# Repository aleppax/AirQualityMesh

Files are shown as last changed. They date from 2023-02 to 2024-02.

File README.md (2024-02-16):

# outdoor air quality station opms logo

current development status: [Proof of Concept.](roadmap.md)

IoT system monitoring outdoor air quality with multiple stations, remote data collection and analytics.
It can work both as a stationary or a roving unit, logging datetime, position and sensor data.

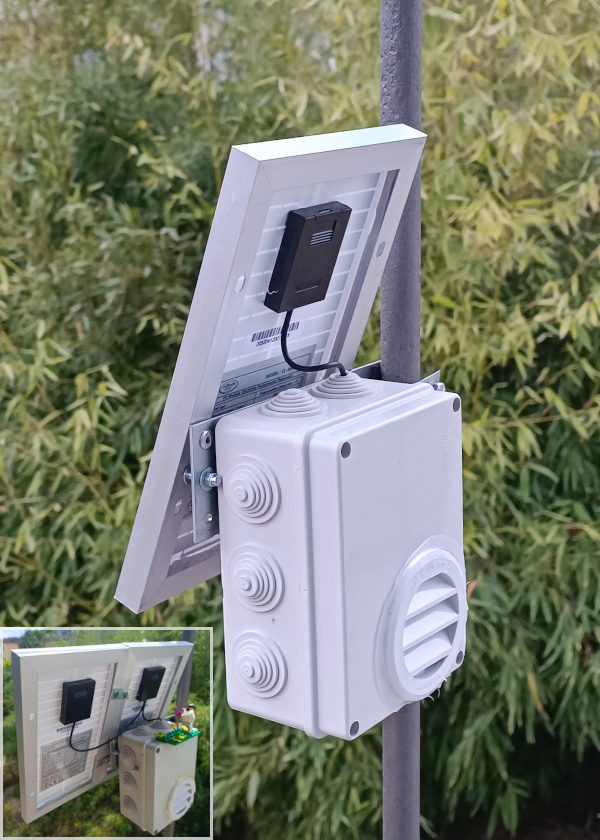
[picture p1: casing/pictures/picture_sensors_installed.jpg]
mainboard rendering an external photo of the installed system


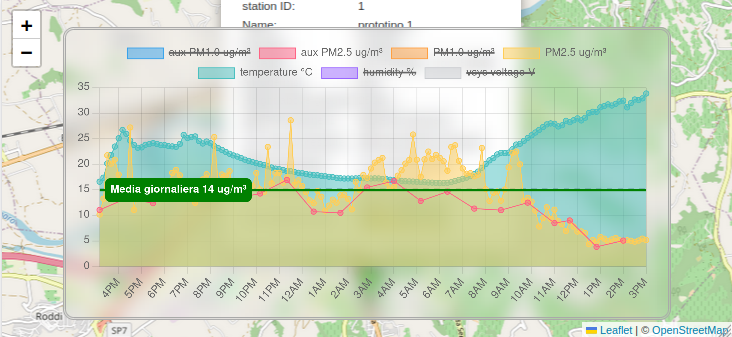
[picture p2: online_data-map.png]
data visualization online charto of data from a single station


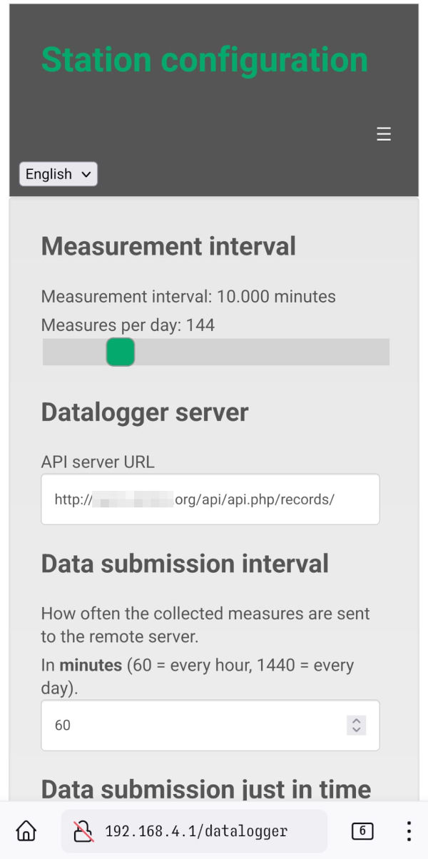
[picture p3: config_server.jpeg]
station configuration on board configuration webserver


## Supported sensors 

|sensor| description | physical dimensions| max connected sensors |
|--|--|--|--|
| pms5003 | PM Sensor PMS5003 | pm1.0 pm2.5 | 2 |
| pms5003T | PM Sensor PMS5003T | pm1.0 pm2.5 humidity temperature | 2 |
| sngcja5 | PM Sensor SN-GCJA5 | pm1.0 pm2.5 | 1 |
| sps30 | PM Sensor SPS30 | pm1.0 pm2.5 | 1 |
| bmp280 | Pressure sensor BMP280 | barometric pressure | 1 |
| aht20 | Humidity and Temperature Sensor AHT20 | humidity temperature | 1 |

* there is an overall max number of 2 connected PM sensors at the same time, regardless of the model. The limit is software, therefore it can be overcome.

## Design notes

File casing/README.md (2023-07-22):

## PCB
 
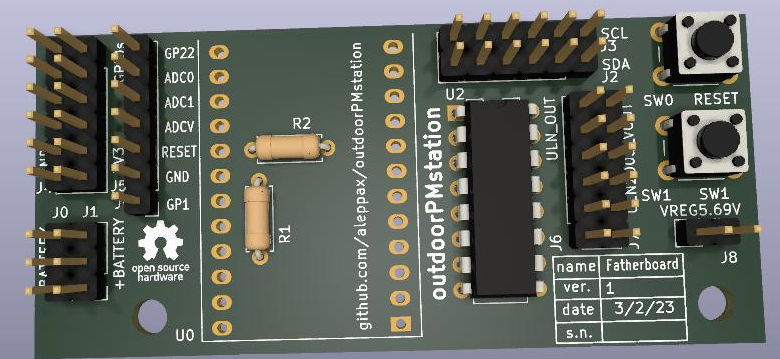
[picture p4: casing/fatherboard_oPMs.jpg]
mainboard rendering mainboard


The PCB design is single sided, has no SMD parts and a minimalistic BOM. Components are on the opposite side of the copper layer. 
Hence it is very straightforward to make it at home both with a CNC or chemicals. 
The main purpose of the PCB is to speed up the assembly but it is better to choose 
terminals that guarantee contact continuity over time since this is an outdoor application partially exposed to weather conditions.
The two resistors are 20K and 30K Ohm, they are used as an external voltage divider to measure the battery voltage. 
We decided to avoid using the internal ADC3 with its own voltage divider because this relies on the WL_GPIO2 of the wireless chip and we didn't want conflicts during wifi communication. If a good precision isn't paramount it is possible to stop using the external circuit in favor of the builtin one.

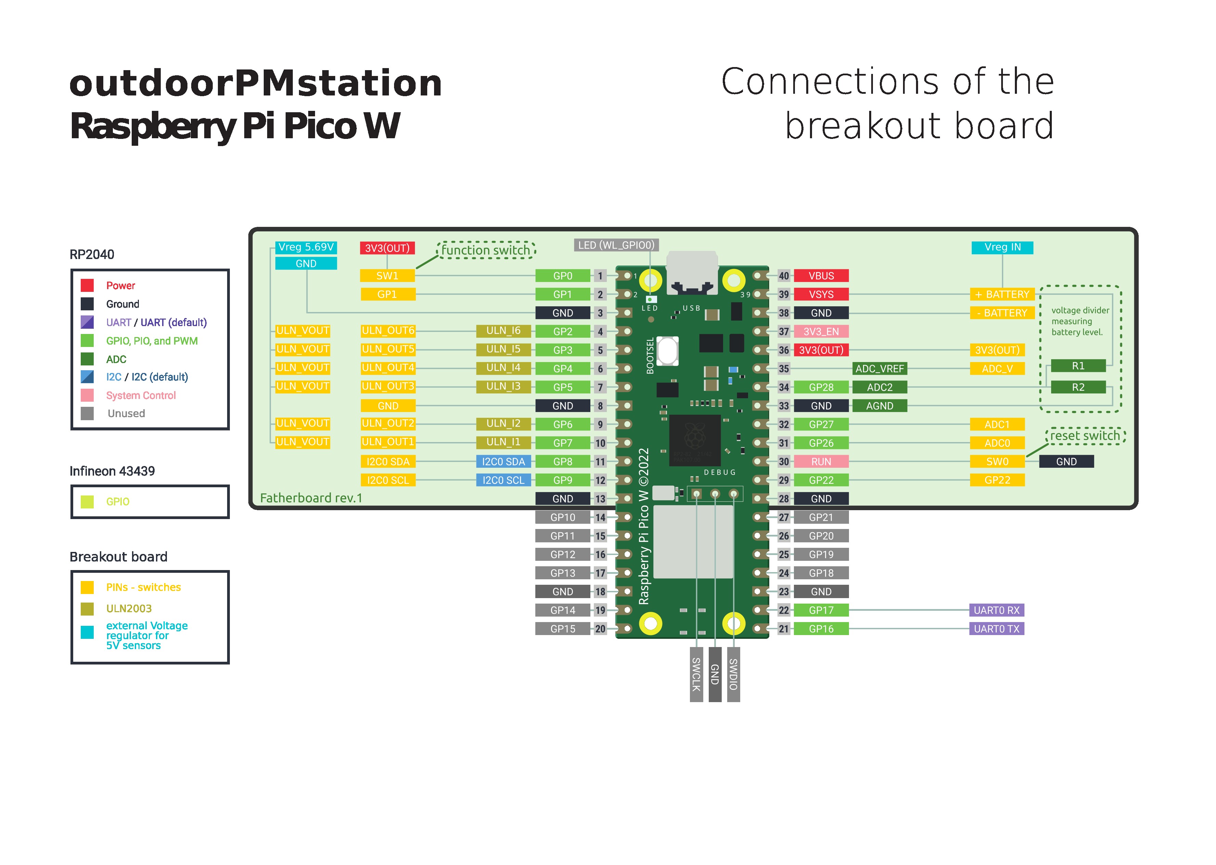
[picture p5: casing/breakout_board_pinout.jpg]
breakout board pinout breakout board


The connection PCB has been designed so that half of the Raspberry Pico, the part where the antenna is located, protrudes, so as to move connection wires and tracks away as far as possible from the transceiver area.

## Case

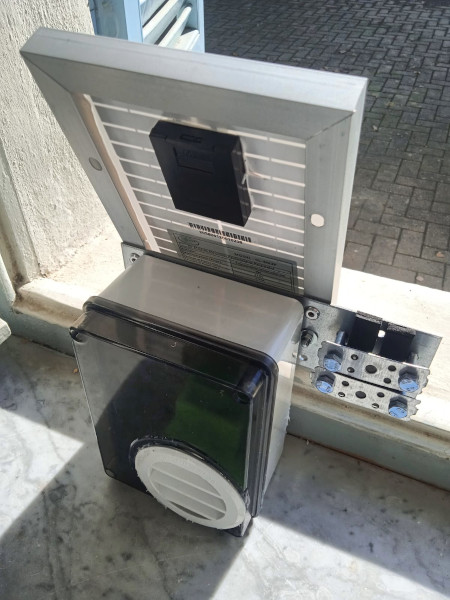
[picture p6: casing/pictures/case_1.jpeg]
front view case front view

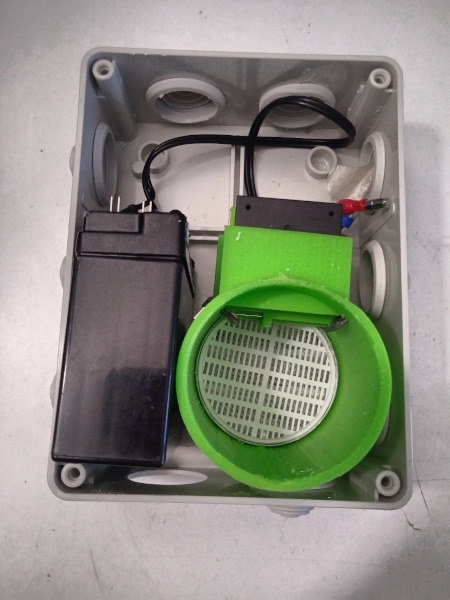
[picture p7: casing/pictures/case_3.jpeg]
battery view 4V battery inside


the casing is designed to be composed mainly of cheap parts available from electrical component suppliers, for which a compact junction box was chosen (150 X 110 X 70 mm, IP 56), commercially available air vents (to which a double layer of mosquito netting was added for greater protection from small insects). Each air vent has an overall opening of 8 cm^2.

## Solar panel

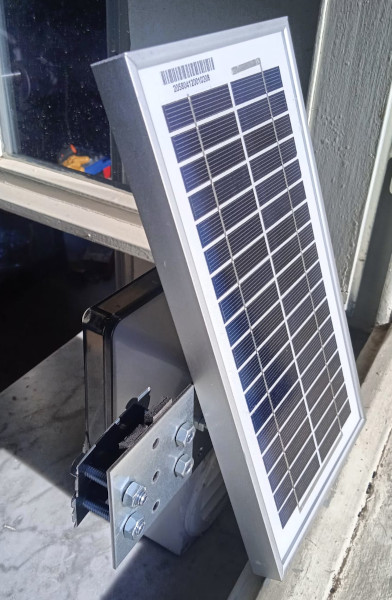
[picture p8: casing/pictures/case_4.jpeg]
rear view case rear view


The solar panel (Cellevia CL-SM3P) is extremely cheap but still slightly oversized, it has the secondary function of protecting the casing from direct solar radiation and has an aluminum frame for easier fixing.

## Fixing 

A sturdy joint plate with screws and nuts for fixing to a post or railing or fence. Different fixing systems will have to be studied according to the location.

## Sensor holder

The only customized component is the sensor fixing structure which allows to house two particulate sensors and possibly a humidity and temperature sensor. Subsequent redesigns could accommodate a small fan in case it is necessary to force a greater air exchange.

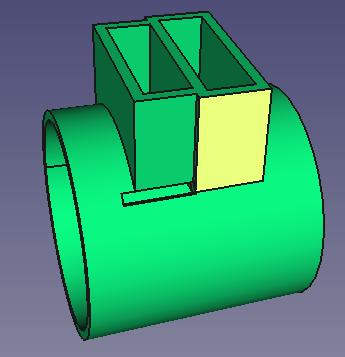
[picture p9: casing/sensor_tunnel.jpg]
mainboard rendering sensor tunnel

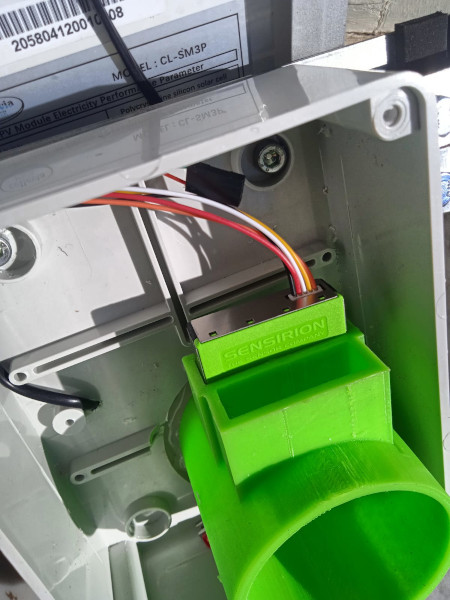
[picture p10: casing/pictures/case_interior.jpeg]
interior case interior view

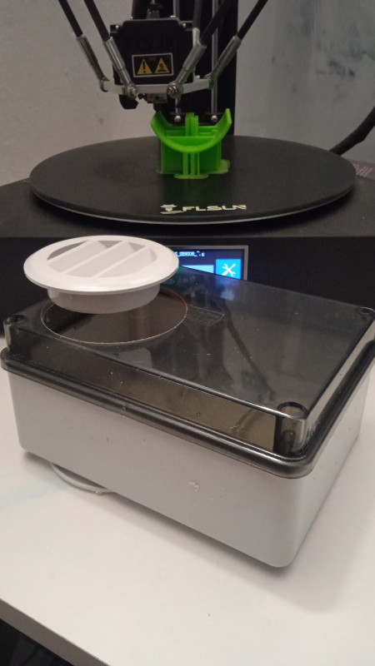
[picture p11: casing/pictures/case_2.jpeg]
assembly 3D printing the sensor holder


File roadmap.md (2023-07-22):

# Roadmap

## Early Proof of Concept

we are investigating many possibilities and the purpose of this stage is to define a roadmap for the Proof of Concept

## Proof of Concept -CURRENT-

At this stage the project is emerging from a glowing cauldron, nothing is permanent and the overall structure of the system is in progress.
We are currently evaluating:
 - [x] WiFi network, data queue, main routine
 - [x] acting as an Access Point and web server to configure the SSID and password from the user (unsecured) and other settings 
 - [x] MQTT connection,REST API
 - [ ] selection of parameters and launch of side projects: humidity, temperature, wind, PM, sound pressure level, traffic counter.
 - [ ] testing sensors: particle matter, sound, wind
 - [ ] batteries, solar panels and power regulators

the purpose of this stage is to define a roadmap for a Minimum Viable Product

## Minimum Viable Product

A minimum working configuration 

 - [x] is powered by battery or power supply and optimizes current usage
 - [x] has a simple case (e.g. a junction box) suitable for outdoor usage
 - [x] allows the user to see sensor measures, setup the WiFi connection and global coordinates via a web interface
 - [x] sync its RTC wit NTP servers
 - [x] update the software if available
 - [x] reads sensors data according to the schedule
 - [x] stores data into a queue when network is unreachable 
 - [x] send measurements via ~~existing (sensors.community)~~ and custom APIs or mqtt to a public server
 - [x] receive and display data to a Home Assistant server
 - [ ] basic documentation

# Alpha

 - [ ] project structure pruning and refactoring
 - [ ] software test coverage and debugging
 - [ ] define features and technical details
 - [ ] define metrological details (operating range, uncertainty, redundancy, metrological traceability, calibration) sensors are not black boxes.
 - [ ] design and test of the enclosure, internal layout, bug-proof and water tightness, thermal performance with different climatic conditions and solar exposition
 - [ ] standard visualization via hosted web server
 - [ ] comprehensive documentation and community involvement 
 
# beta
- optional network connection via GSM - LoRa wan.
- test with the help of early users
- collect data
- improved access point interface
- improved visualization server side via Leaflet

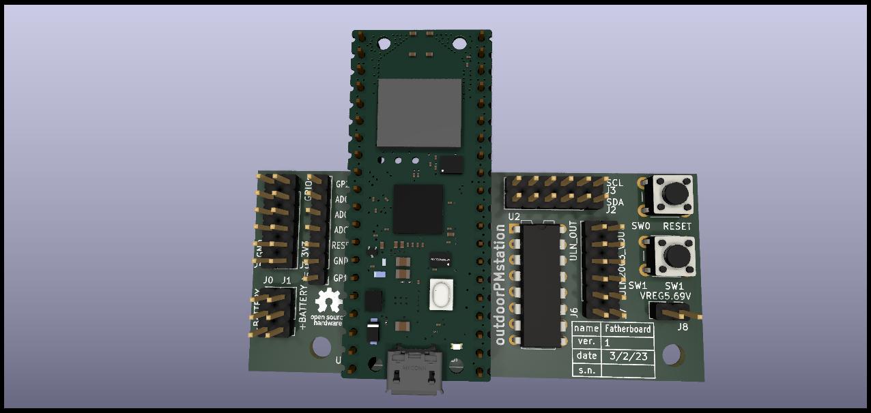
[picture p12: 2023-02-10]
fatherboard_oPMs2.jpg

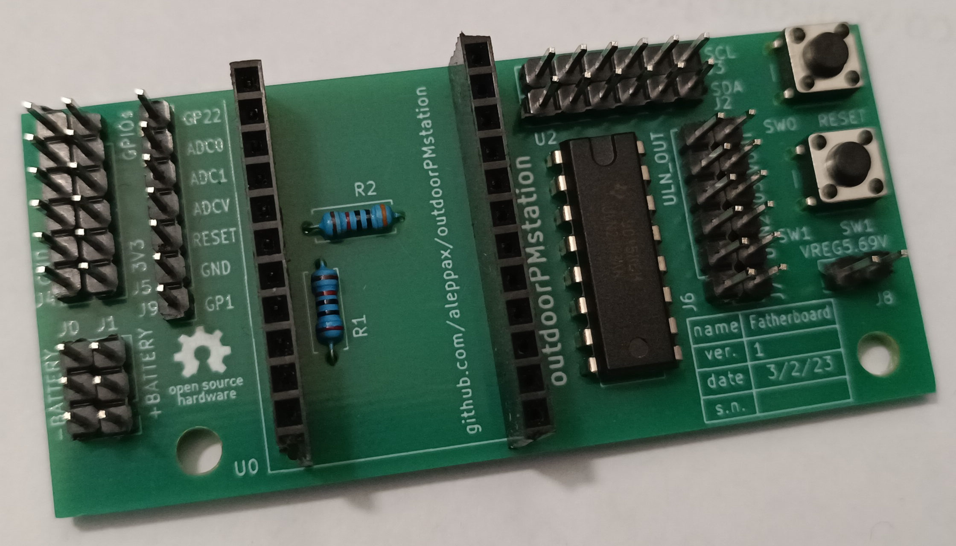
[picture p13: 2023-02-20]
casing/pictures/fatherboard_v1.jpg

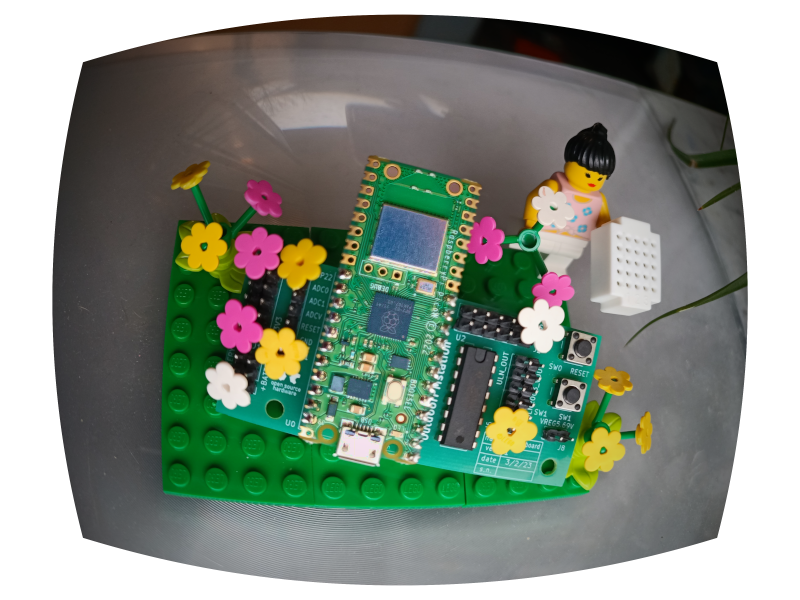
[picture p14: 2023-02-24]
opms_Paradisa_Flowers.png

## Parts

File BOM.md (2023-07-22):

# Bill of materials

## version based on Raspberry Pico W
|part name|quantity|Manufacturer|Manufacturer symbol|
|---|---|---|---|
|Raspberry Pico W|1|Raspberry Pi Ltd.|Raspberry Pi Pico W|
|AHT20+BMP280 breakout board|1|temperature humidity sensor+pressure temperature sensor|AHT20+BMP280|
|solar panel|1||5-10W depending on conditions|
|4V 3Ah lead acid battery|1|many brands|67x75x35 mm|
|PM sensor|1|Sensirion|SPS30|
|PM sensor|1|Panasonic|SN-GCJA5|
|junction box|1|many brands|(150X110X70mm, IP 56)|
|circular air vent|2|La ventilazione|T63B|
|mosquito net|2x80mm diameter|------------|-------------------|
|joint plate|1|------------|60x200x2,5 mm|
|2A DC-DC Booster|1|------------| MT3608 |
|STEP DOWN converter|1|------------| MP1584 |
|sensor tunnel|1|outdoorPMstation|SENSOR_TUNNEL-Body.stl|

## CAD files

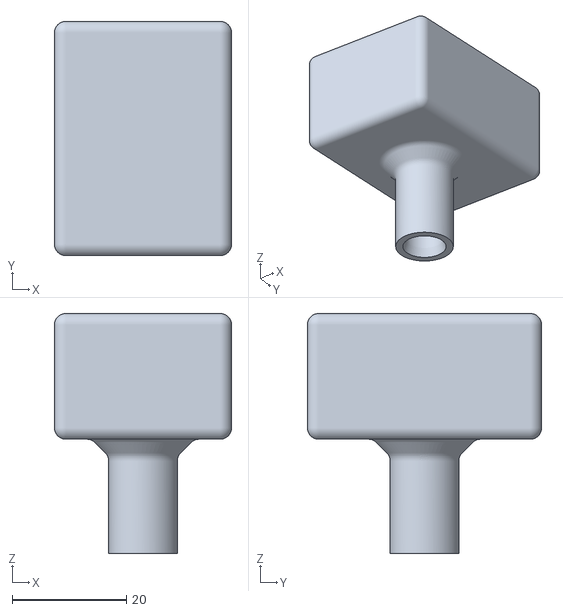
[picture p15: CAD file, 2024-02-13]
casing/GY-NEO6M_case-Assembly.stl
31.0 x 41.0 x 42.0

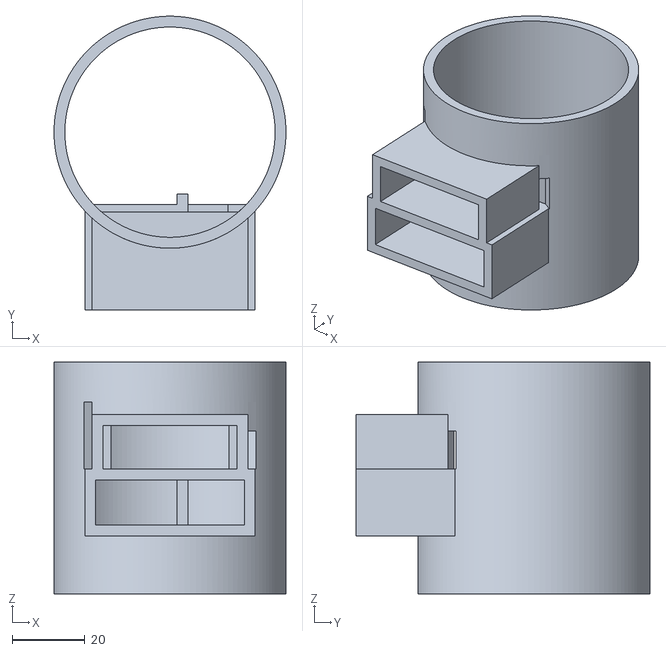
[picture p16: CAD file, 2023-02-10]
casing/SENSOR_TUNNEL-Body.stl
64.0 x 81.0 x 64.0

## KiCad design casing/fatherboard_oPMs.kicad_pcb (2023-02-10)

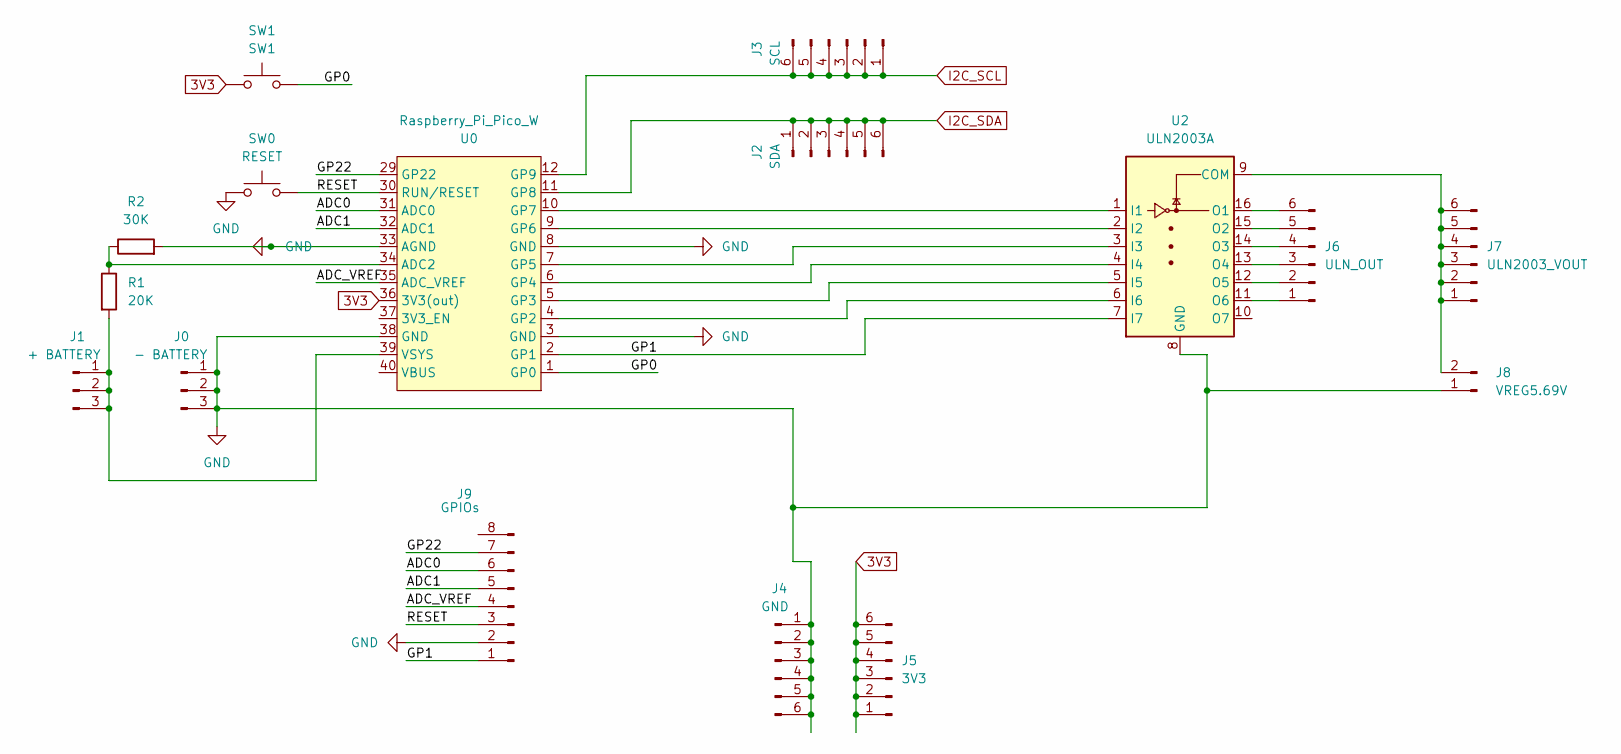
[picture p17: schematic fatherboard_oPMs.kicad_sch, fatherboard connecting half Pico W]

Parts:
J0: - BATTERY; PinHeader_1x03_P2.54mm_Vertical
J1: + BATTERY; PinHeader_1x03_P2.54mm_Vertical
J2: SDA; PinHeader_1x06_P2.54mm_Vertical
J3: SCL; PinHeader_1x06_P2.54mm_Vertical
J4: GND; PinHeader_1x06_P2.54mm_Vertical
J5: 3V3; PinHeader_1x06_P2.54mm_Vertical
J6: ULN_OUT; PinHeader_1x06_P2.54mm_Vertical
J7: ULN2003_VOUT; PinHeader_1x06_P2.54mm_Vertical
J8: VREG5.69V; PinHeader_1x02_P2.54mm_Vertical
J9: GPIOs; PinHeader_1x07_P2.54mm_Vertical
R1: 20K; R_Axial_DIN0207_L6.3mm_D2.5mm_P7.62mm_Horizontal
R2: 30K; R_Axial_DIN0207_L6.3mm_D2.5mm_P7.62mm_Horizontal
SW0: RESET; SW_PUSH_6mm_H5mm
SW1: SW1; SW_PUSH_6mm_H5mm
U0: Raspberry_Pi_Pico_W; DIP_Socket-24_W11.9_W12.7_W15.24_W17.78_W18.5_3M_224-1275-0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
U2: ULN2003A; DIP-16_W7.62mm

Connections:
3V3: J5.1, J5.2, J5.3, J5.4, J5.5, J5.6, SW1.1, U0.36 (3V3(out))
/ADC0: J9.6, U0.31 (ADC0)
/ADC1: J9.5, U0.32 (ADC1)
/ADC_VREF: J9.4, U0.35 (ADC_VREF)
/GP0: SW1.2, U0.1 (GP0)
/GP1: J9.1, U0.2 (GP1), U2.7 (I7)
/GP22: J9.7, U0.29 (GP22)
/RESET: J9.3, SW0.2, U0.30 (RUN/RESET)
GND: J0.1, J0.2, J0.3, J4.1, J4.2, J4.3, J4.4, J4.5, J4.6, J8.1, J9.2, R2.2, SW0.1, U0.3 (GND), U0.8 (GND), U0.33 (AGND), U0.38 (GND), U2.8 (GND)
I2C_SCL: J3.1, J3.2, J3.3, J3.4, J3.5, J3.6, U0.12 (GP9)
I2C_SDA: J2.1, J2.2, J2.3, J2.4, J2.5, J2.6, U0.11 (GP8)
unnamed: J1.1, J1.2, J1.3, R1.2, U0.39 (VSYS)
unnamed: J6.1, U2.11 (O6)
unnamed: J6.2, U2.12 (O5)
unnamed: J6.3, U2.13 (O4)
unnamed: J6.4, U2.14 (O3)
unnamed: J6.5, U2.15 (O2)
unnamed: J6.6, U2.16 (O1)
unnamed: J7.1, J7.2, J7.3, J7.4, J7.5, J7.6, J8.2, U2.9 (COM)
unnamed: R1.1, R2.1, U0.34 (ADC2)
unnamed: U0.4 (GP2), U2.6 (I6)
unnamed: U0.5 (GP3), U2.5 (I5)
unnamed: U0.6 (GP4), U2.4 (I4)
unnamed: U0.7 (GP5), U2.3 (I3)
unnamed: U0.9 (GP6), U2.2 (I2)
unnamed: U0.10 (GP7), U2.1 (I1)

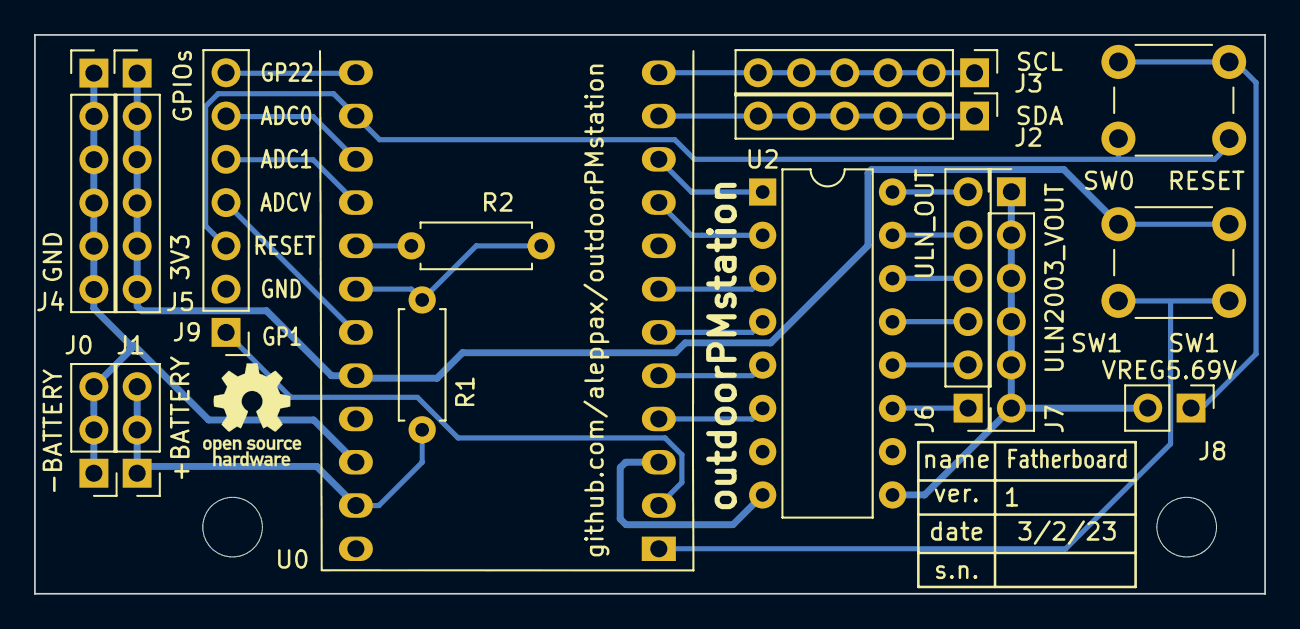
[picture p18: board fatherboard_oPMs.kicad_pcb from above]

Board: 2 copper layers, 72.2 x 32.8 mm, 16 parts (0 on the bottom side), 26 nets.

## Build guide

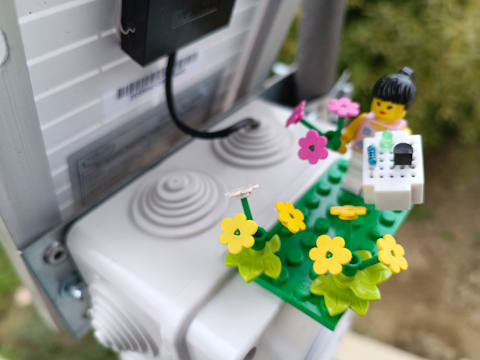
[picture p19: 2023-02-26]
casing/pictures/picture_sensors_installer.jpg

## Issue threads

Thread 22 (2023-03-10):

pico not exiting lightsleep but hanging

aleppax, 2023-03-10:
The problem is known
But the solution suggested doesn't seem to solve all the problems.
Someone should try to debug with swd

aleppax, 2023-03-12:
https://github.com/tomjorquera/pico-micropython-lowpower-workaround/blob/master/lowpower.py
Looking into this could be helpful

aleppax, 2023-03-12:
While doing more tests, I realized that the low level of current during lightsleep can't occur when the LED pin output is initialized. Therefore, since we would have, but currently do not use it anyway, I'll remove it from the init process.

aleppax, 2023-03-14:
this is blocking. The problem still occurs with "&& cyw43_poll != NULL" in modmachine.c
after many minutes (?) that REPL connection is lost and is unresponsive, thonny console resets and shows REPL prompt, but pico doesn't execute main.py as usual. I'm not using boot.py

aleppax, 2023-03-16:
18 hours without lightsleep stopping, it seems to me that at least in this installation the problem is solved, I await confirmation from @robferrero to close this issue.

robferrero, 2023-03-16:
I'm still testing , actually I find useful info here too  https://forum.micropython.org/viewtopic.php?f=21&t=12657&p=68842&hilit=sleep+wlan.deinit+wlan.deinit#p68842

aleppax, 2023-05-12:
another few days and if the problem doesn't occur any more I'll close this issue.

Closed 2023-05-17.

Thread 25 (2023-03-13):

add Web socket connection to interface

aleppax, 2023-03-13:
Add realtime sensor measures to station Web interface.

aleppax, 2023-04-15:
also, merge the captivate portal with the realtime sensor monitor.

aleppax, 2023-06-16:
Most of the work is done, there is still the websocket connection to implement, it will be used to start a measurement cycle (with preheating) and to fetch the measures.

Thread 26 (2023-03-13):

while using I2C bus, all clients must be powered on

aleppax, 2023-03-13:
it is impossible to communicate with a i2c slave if another one connected to the same bus is powered down.
The simplest solution is that at least during the commuications they must be on.

aleppax, 2023-03-14:
should have been addressed with commit d54029f

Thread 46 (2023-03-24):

i2c sensors plug and play

aleppax, 2023-03-24:
restructuring the sensors module (or the drivers) in order to initialize and use only I2C sensors that are available, loading the appropriate driver and calling the right function when a measure is requested.

aleppax, 2023-03-28:
#47 should do.

aleppax, 2023-03-29:
#47 merged

Closed 2023-03-29.

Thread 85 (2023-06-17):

online configurator

aleppax, 2023-06-17:
There are many aspects requiring some sort of configuration involving the power economy of the system:
- installation: the choice between an optimal installation and one coping with physical obstacles
- dimensioning of the battery
- dimensioning of the solar panel
- configuring the software
- autonomy requirements and acceptable duration of power failure events

and many variables:
- variable requirements (number and power requirements of sensors, frequency of measurement,...)
- variable conditions (latitude, geographical obstacles, sunlight exposure, long periods of overcast sky)

Furthermore a tradeoff between cost and performance should be chosen during the configuration phase, and a system designed for a particular set of conditions may fail in case of software configuration changes.
There are many other considerations adding to the complexity of this particular design phase, and there are essentially two approaches to the problem:
- empirical: the first requires the installation of a standard system fulfilling minimum requirements, then a validation of the system and, if needed, a possible software and hardware modification with subsequent resizing of the power supply, by trial and error, until a condition of self-sufficiency is reached
- by design: the second involves an a priori calculation and sizing of the energy requirements of the system with validation of the design in the field.
The first step to implement the latter approach is to define an equation involving all the relevant variables. A further step will be implementing an online configuration page using this equation under the hood.

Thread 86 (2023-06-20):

replace daylight energy saving criteria

aleppax, 2023-06-20:
Replace the option to send data only between two hours with an option to send data only when battery voltage is greater than a certain level, useful to send over the network only when the solar panel is charging the system.

aleppax, 2023-06-20:
moreover the logic behind the status of charging of the battery isn't working: the datalogger sends "battery is charging" = False even when it is evident that it is true.

aleppax, 2023-06-21:
#87 addresses this issue.

Closed 2023-06-21.

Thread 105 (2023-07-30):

add colored map visualization

aleppax, 2023-07-30:
add to the map a colored visualization (algebric or statistic interpolation) of inferred values. A good starting point is the type of visualization made by [LASS](https://pm25.lass-net.org/GIS/IDW/) for Taiwan. Maybe a different interpolation logic from IDW should be used.

aleppax, 2023-07-30:
[the GitHub repository of the reference](https://github.com/HuangLiPang/pm2.5-idw-map)

aleppax, 2023-10-07:
the visualization part is complete, now tested with random colors displayed over the map.
But the interpolation of points is in an early stage. There are so many ways of accomplish this, IDW, linear interpolation, a web assembly ML model...
a simplicistic idea is to use a roving sensor to collect a network of time-related samples, then design a diffusion model which propagates the single values to the whole area of influence.
This part can be used as a viewer for different models.
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

Closed 2023-10-07.

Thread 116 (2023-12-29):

rover logic

aleppax, 2023-12-29:
adding configurable rover logic. This is not intended as in "a self driving software delivering the sensors around the globe" but more as a human machine interface signalling to the operator when the station is collecting data, if the speed is correct, if the gps signal is detected, and so on.

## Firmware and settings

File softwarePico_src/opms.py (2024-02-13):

from libs import cron, datalogger, filelogger, logger, mqttlogger, sensors, wlan
from machine import reset, freq, mem32
import micropython

# cron could also be named 'core'
micropython.alloc_emergency_exception_buf(100)
reset_cause = mem32[0x40058008]
# https://github.com/orgs/micropython/discussions/10858#discussioncomment-5504000
# You'll get 0 for normal power on. 1 for watchdog and 2 for machine.reset.
logger.info('booting. Reset cause ' + str(reset_cause))
freq(65000000)
logger.info('Clock speed set to ' + str(freq()))
#this test works also before initializing i2c and sensors
sensors.check_low_power()
# init system
logger.check_fs_free_space()
#init I2C and GPIO. access a port with gpio['GP2']
i2c, gpio = cron.initialize_board()
sensors.init(i2c, gpio)

#button SW1 pressed at startup: entering configuration mode
if gpio['GP0'].value() is 1:
    wlan.serve_captive_portal()

def updates():
    # connect to wifi only if updates are required
    ntp_scheduled = cron.check_ntp_schedule()
    update_scheduled = cron.check_software_schedule()
    if (ntp_scheduled or update_scheduled):
        if wlan.connect():
            if ntp_scheduled:
                cron.update_ntp() # every NTPsync_interval
            if update_scheduled:
                cron.check_software_updates() # every update_interval
                cron.update_software()
        wlan.turn_off()
        if cron.check_ntp_schedule():
            logger.info("Failed to update the clock. Rebooting.")
            cron.lightsleep_wrapper(180000)
            reset()

def updates_rover():
    # fetch datetime from GNSS, do not attempt any software update
    if sensors.update_gnss_time():
        return
    logger.info("Failed to update the clock via satellite. Trying via mobile hotspot and NTP.")
    if wlan.connect():
        cron.update_ntp()
    if cron.check_ntp_schedule():
        logger.info("Failed to update the clock. Rebooting.")
        cron.lightsleep_wrapper(20000)
        reset()

def send_values():
    opms_logged = filelogger.write_opms(sensors.measures) # current measures immediately saved to file
    # if using opensensemap, write current measures also to specific file queue
    if datalogger.opensensemap_enable:
        opensensemap_logged = filelogger.write_opensensemap(sensors.measures)
    if cron.check_data_schedule(sensors.battery_values[2],sensors.leadacid.min_charging_voltage):
        # connect to wifi only if sending data is scheduled
        if wlan.connect():
            # submission of stored data to servers
            attempts = datalogger.attempts()
            while attempts > 0:
                attempts -= 1
                opms_file_lines = filelogger.read_opms()
                if len(opms_file_lines) != 0:
                    if datalogger.send_data_list(opms_file_lines):
                        filelogger.write_remaining_opms_data()
                if datalogger.opensensemap_enable:
                    opensensemap_file_lines = filelogger.read_opensensemap()
                    if len(opensensemap_file_lines) != 0:
                        if datalogger.send_opensensemap_data_list(opensensemap_file_lines):
                            filelogger.write_remaining_opensensemap_data()
            #if errors occurred, try to submit current data to remote servers
            if not opms_logged:
                opms_logged = datalogger.send_data(sensors.measures)
            if datalogger.opensensemap_enable:
                if not opensensemap_logged:
                    opensensemap_logged = datalogger.send_opensensemap_data(sensors.measures)
            if opms_logged:
                cron.update_last_data_sent()
                mqttlogger.send_data(sensors.measures)
            else:
                opms_logged = filelogger.write_measures(sensors.measures,config.filelogger['filename'])
        wlan.turn_off()
    # retry writing to file
    if not opms_logged:
        opms_logged = filelogger.write_measures(sensors.measures,config.filelogger['filename'])
    if datalogger.opensensemap_enable:
        if not opensensemap_logged:
            opensensemap_logged = filelogger.write_measures(sensors.measures,config.filelogger['opensensemap_filename'])
    if not opms_logged:
        logger.error('current measures cannot be saved or sent to OPMS server.')
    if datalogger.opensensemap_enable:
        if not opensensemap_logged:
            logger.error('current measures cannot be saved or sent to OpenSenseMap API server.')


if cron.is_rover():
    sensors.measure_battery()
    sensors.wakeup()
    updates_rover()
    cron.lightsleep_wrapper(cron.preheat_time())
    while True:
        # uses GP1 as digital input. Bistable switch, enables moving and recording
        if not gpio['GP1'].value():
            cron.lightsleep_wrapper(10000)
            continue
        # set roving to True (either digital pin or communicate status, rover can start/continue his path)
        cron.enable_roving()
        # locate GNSS position and refine
            # if no fix: infer
            # if fix: store lat lon
        # compare position with latest record
            # if distance < interval distance: wait, goto locate GNSS
            # if distance > interval distance: continue
        # set roving to False (rover should stop in a safe spot)
        cron.disable_roving()
        # measure serie, average and store/send
        sensors.measure(logger.now_DTF())
        send_values()
        sensors.check_low_power()
else:
    while True:
        # before anything that could change the reading
        sensors.measure_battery()
        # check if it's time to look for NTP or software updates
        updates()
        # if a measurement is scheduled during this wake cycle, do the job
        if cron.do_measure:
            sensors.wakeup()
            # sleep while sensors preheat
            cron.lightsleep_wrapper(cron.preheat_time())
            sensors.measure(logger.now_DTF())
            send_values()
        # a way to exit the while cycle if power is low
        sensors.check_low_power()
        # otherwise work done, rest until next task
        cron.lightsleep_until_next_cycle()   

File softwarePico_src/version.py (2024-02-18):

version = 67
folders = ['/', '/libs', '/html', '/logs']
#updates or new files. this file is manually updated and can only add or modify files or add folders
updated_files = {
    '/'     : [],
    '/libs/' : ['config.py','sensors.mpy'],
    '/logs/' : [],
    '/html/' : [], 
}
# full update requires a list of all files
all_files = {
    '/'     : ['main.py','opms.mpy'], # there is no need to include version.py
    '/libs/' : ['ahtx0.mpy','bmp280.mpy','config.py','cron.mpy','datalogger.mpy','filelogger.mpy','__init__.py','leadacid.mpy','logger.mpy','microdot.mpy','micropyGPS.mpy','mqttlogger.mpy','neo6m.mpy','picosngcja5.mpy','pms5003.mpy','qmc5883.mpy','sensors.mpy','simple.mpy','sps30.mpy','wlan.mpy'],
    '/logs/' : [],
    '/html/' : ['portal.html', 'portal-advanced.html', 'portal-basic.html', 'portal-datalogger.html', 'portal-mqtt.html', 'portal-network.html', 'portal-status.html', 'portal-syslogger.html', 'portal-opensensemap.html'], 
}

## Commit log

2022-12-17 Create BOM.md
    added stripped down BOM for the alpha development stage.
2023-01-10 added basic networking, logger and config modules. added sngcja sensor module. restructured initialization
2023-01-13 added basic battery monitor, scheduler and bmp180 library
2023-01-14 better integration of the sensor module
2023-01-17 initial breadboard layout of the main components
    [development-layout1.fzz]
2023-01-17 added initial development layout1
    breadboard layout
    [development-layout1.fzz]
2023-01-18 first revision of the sensors holder
    [SENSOR_TUNNEL-Body.stl]
2023-02-03 layout replaced by new pcb design
    [development-layout1.fzz]
2023-02-03 single side PCB mainly used to connect everything
    The PCB design is single sided, has no SMD parts and few parts. Hence it is very straightforward to make it at home both with a CNC or chemicals. The main purpose of the PCB is to speed up the assemb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
    [fatherboard_oPMs.kicad_pcb, fatherboard_oPMs.kicad_sch]
2023-02-03 added rendering of the main board
2023-02-13 Add files via upload
    image of the 3d printed part used to hold the sensors
2023-02-13 Add files via upload
    some pictures of the prototype
2023-02-13 Update BOM.md
    updated BOM
2023-02-17 added SHT31 temp humidity sensor, setting the measurement function
2023-02-18 used AHT20 and BMP280 instead of SHT31 sensors
2023-02-19 fixed many errors, added randomizer for ntp server
    [version.py]
2023-02-20 picture of the first batch of PCB
2023-02-23 Update BOM.md
    replaced humidity-temp-pressure sensor
2023-02-23 dealing with a couple of exceptions
2023-02-24 first board assembled
2023-02-25 missing import, new i2c bus speed setting
2023-02-25 somewhere we were trying to print an error object instead of its string representation
2023-02-27 Update README.md
    showing current progress
2023-02-27 new low power mode when battery is low. enabled logging data to file when online datalogger fails adapted sensor library
2023-02-28 averaging n measures for each sensor, simpler wakeup cycle, switching off sensors there was a problem with I2C when I tried to gently disable the sensor SPS30, therefore the working solution is to dr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
    now config has two new settings:
    sensors = {
    'average_particle_measurements' : 20,
    'average_measurement_interval_ms' : 1000,
    }
    to determine the timespan and the number of measurements used to get an average
    the default frequency of measurement ('measuremens_per_day') has been reduced to 144 (1 per 10 minutes)
    because the battery is already undersized for the purpose and averaging 20 measurements
    led to nearly doubling the battery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
2023-02-28 a small delay was missing before starting sps30 sensor
2023-03-01 fixed error when updating online a reboot is required
    [version.py]
2023-03-03 wrong import statement resulted in never exiting from low power mode
2023-03-04 updatet version file with low power mode and NTP fixes
    [version.py]
2023-03-05 fix su mqttlogger.py e save file di Home Assistant
2023-03-07 fixed many errors. Added the option to test the code without wdt and without sensors in config.py 'disable_sensors' and 'use_wdt'
    [version.py]
2023-03-07 rebased snippets used to add autocleaning routine to SPS30 sensor
2023-03-08 battery cherge level is increased to 4,95V
2023-03-08 DEEPSLEEP_RESET do not exists for the pico
2023-03-11 separate cycle for auxiliary PM sensor the battery requirement halves.
2023-03-11 reduced minimum battery level after considering different producers datasheet
2023-03-11 modified battery limits
2023-03-13 led pin is causing troubles
    Better not using it since it is connected to the wifi chip and can increase the current usage during lightsleep, even if we think that wifi has been turned off. In this case it's not true that LED co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
2023-03-14 connect to wifi only if update is scheduled, other power optimizations
2023-03-14 reverting separate sensor usage because the I2C bus can't be used anyway in a separate manner
2023-03-16 removed use of wifi enable pin 23
2023-03-17 changed barometric pressure units to something more common
2023-03-21 trying to achieve a more accurate voltage reading
2023-03-22 Update cron.py
    filter dicts
2023-03-24 some initial check of the i2c bus
2023-03-24 missing condition led to not write new values into config file
2023-03-24 logging vsys voltage
2023-03-24 updated db structure adding voltage value
2023-03-28 revamping of the sensor module. Sensor drivers are loaded and measures are taken for detected sensors. otherwise the cycle continues without errors caused by a missing sensor. Code can't solve an har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
    [version.py]
2023-03-29 swapped channels
    Swapped ch1 and ch 2 of pm sensor
2023-03-29 swapped channels
    Swapped ch1 with ch2. Aux sensor is connected to ch2
2023-03-29 avoiding errors when no sensor is connected and all values are zero, than calculating the dew point results in an error trying to solve log(0) Caution: the value of the class name of module ahtx0 has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
2023-04-01 added error handling when connection drops and datalogger can't send data
    [version.py]
2023-04-01 insert maximum value for keepalive in mqtt
2023-04-03 fixed problem: global config wasn't updated after module reload. Solution: there is non more a global config. every module loads config internally. Now cron does what was done by config.
    [version.py]
2023-04-06 a missing else clause led to losing current measurements in case of connection failed
    [version.py]
2023-04-08 battery measurement is done before anithing else
2023-04-11 added logging of reset cause, cleaned logger module
    [version.py]
2023-04-14 Update main.py
    Moved sensors.shutdown() inside sensors.measure()
2023-04-14 Update sensors.py
    Moved sensors shutdown inside measure
2023-04-15 loosen the criteria for considering the low power phase over
    [version.py]
2023-04-18 fixed error of memory exhausted when using urequests
    [version.py]
2023-04-21 trying to avoid errors when sending measurements to server. socket.settimeout seems to work on RP pico.
    [version.py]
2023-04-21 Update config.py
    configured the default update repository, currently set to updates/concept
2023-04-25 filter log levels, minor changes
2023-04-27 added patched firmware for raspberry pico W, patch from https://github.com/micropython/micropython/pull/10803
2023-04-27 Update filelogger.py
    Replaced print statement with logger function
2023-04-27 Update filelogger.py
    Replaced print() with logger calls
2023-04-29 used different variable names between different modules, just in case... added more logging to understand why lines not sent are not written back to file.
2023-05-11 added erroe handling in case of timeout of file download
2023-05-11 replaced print statements with logger entries
2023-05-20 added precompiled firmware with micropython PR #8968, just in case someone would try to test it. Two small but important edits: datalogger should use unsecure http for two reasons: the micropython im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
2023-06-06 further improvement, displaying sensors list in web interface
2023-06-15 Update roadmap.md
    updating current development progress
2023-06-15 added restart button to webconfig, disabled WDT during wireless configuration
2023-06-21 renamed directories, replaced night power saving and pruned unnecessary functions
    [opms.py, version.py]
2023-06-24 adding sensor PMS5003 with UART communication
2023-06-24 fixed wrong behaviour of UART after lightsleep
2023-06-24 more resilient logic, completed implementation behind main PM sensor and auxiliary ones: if a sensor is the main sensor, data are saved to 'pm2.5' and 'pm1.0', if it is auxiliary, data are saved to '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
2023-06-24 added possibility to connect two PMS5003 to different UART pins
2023-06-25 edited sensors module to allow using two pms5003 together
2023-06-25 packed options to function wrapper around measurements, added temperature and humidity option for pms5003T
2023-06-25 correct scale of measurement for temperature and humidity of pms5003
2023-07-01 added LED signalling functionality started designing the web map, currently still WIP
    [fatherboard_oPMs.kicad_sch]
2023-07-03 chart updates when switching from one marker to another
2023-07-27 added logic switching between rover mode and station mode
2023-09-30 opensensemap setting configuration via embedded webserver added 3d model of GPS enclosure
    [GY-NEO6M_case-Assembly.stl]
2023-10-07 changed version update logic, file naming removed print statements and other fixes
    [version.py]
2023-10-21 fixed web interface listing sensors
2024-02-15 added a button to scroll the chart backward in time
2024-02-15 fixed error switching from one station to another
2024-02-18 added logic to use a recirculation fan inside the measurement chamber
2024-02-20 restored previous firmware since the current code requires some adjustment to allow online updates with the newest firmware. Didn't noticed before.
